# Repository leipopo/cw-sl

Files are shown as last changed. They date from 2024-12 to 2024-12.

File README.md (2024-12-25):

# cw-sl
超轻大导轮，适用于禧玛诺十二速后拨

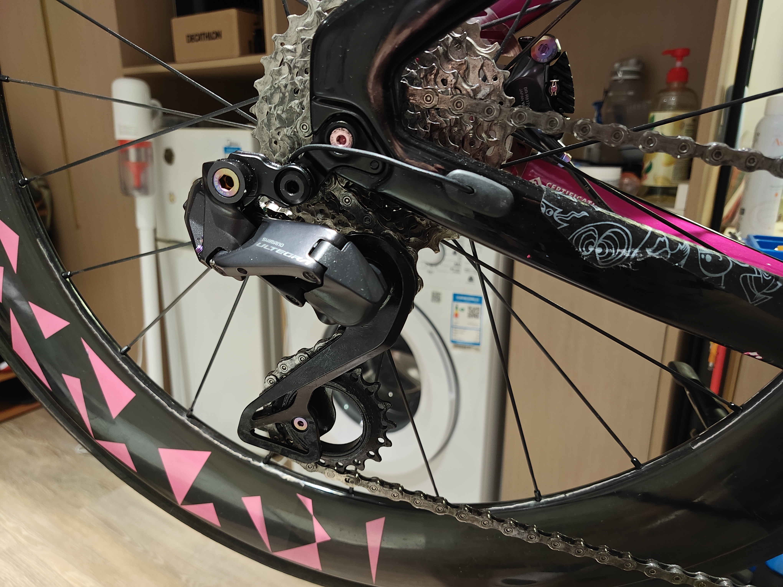
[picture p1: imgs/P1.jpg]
整体效果


# 注意！注意！注意！
本项目定位为超轻毒品件，本设计不做任何质量保证，不承担由此产生的任何安全风险。

# 减重逻辑
禧玛诺原装导轮使用了一颗696rf轴承，此尺寸下的不锈钢轴基本动载约在250lbf左右静载90lbf左右。而大导轮使用的6709轴承的基本动静载约为360/330左右。
参考igus对其生产的塑料轴承和同尺寸普通钢制轴承的动静载的相对比例关系，以及下导轮轴承多工作在低速/静止无冲击的工况，可以初步判断使用塑料6709轴承或许也能满足使用要求。
又进一步分析导轮轴承各部件工作状态：1.内圈局部受高频次的循环载荷，其余地方不受载；2.外圈受低频次的循环载荷，且整个轨道循环频次相同。若采用相同的材质，外圈寿命会远高于内圈。
那直接用塑料做外圈，将齿与外圈做在一起，省去轴承外圈的重量可以进一步减小大导轮重量。于是便有了此项目

# 优化部分

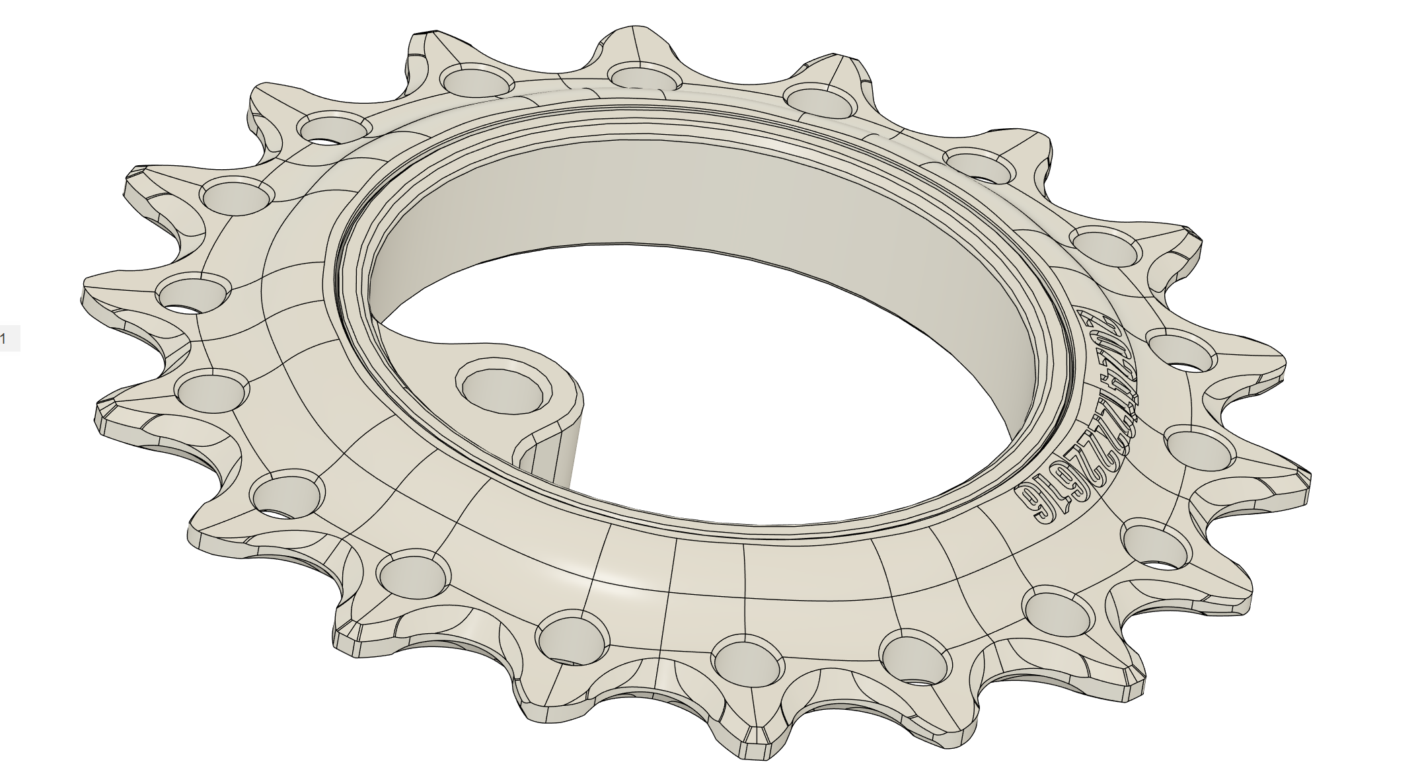
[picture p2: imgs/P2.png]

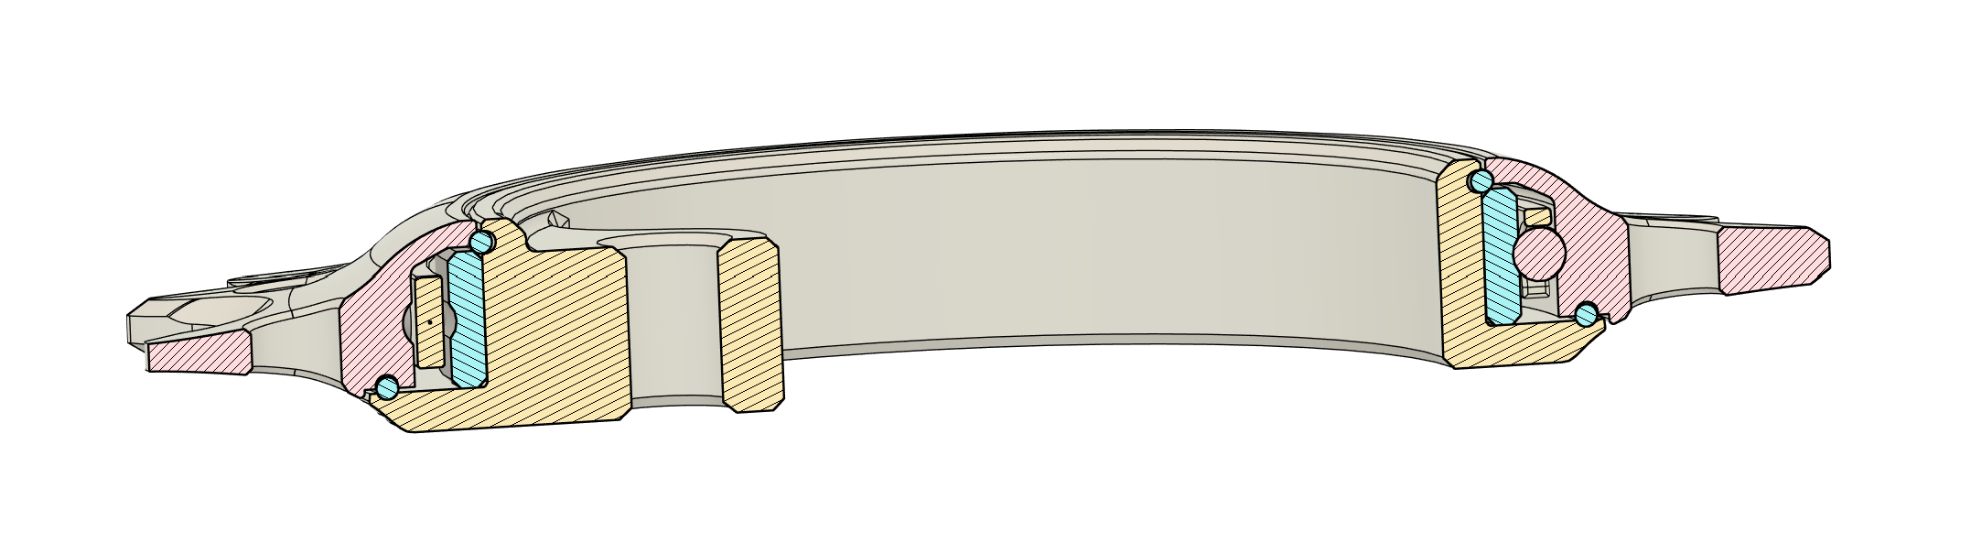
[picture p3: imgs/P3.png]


1. 通过链条路径包络切削出齿形以兼容禧玛诺12s链条的正负齿；
2. 齿端面切割为摆线，优化链条啮入噪声；
3. 齿部与链轮整体光滑，减小风阻；
4. 双面接触式密封，延长维护周期；

# 实测效果
1. 输入功率120w下，损耗功率与原装导轮无差异；
   
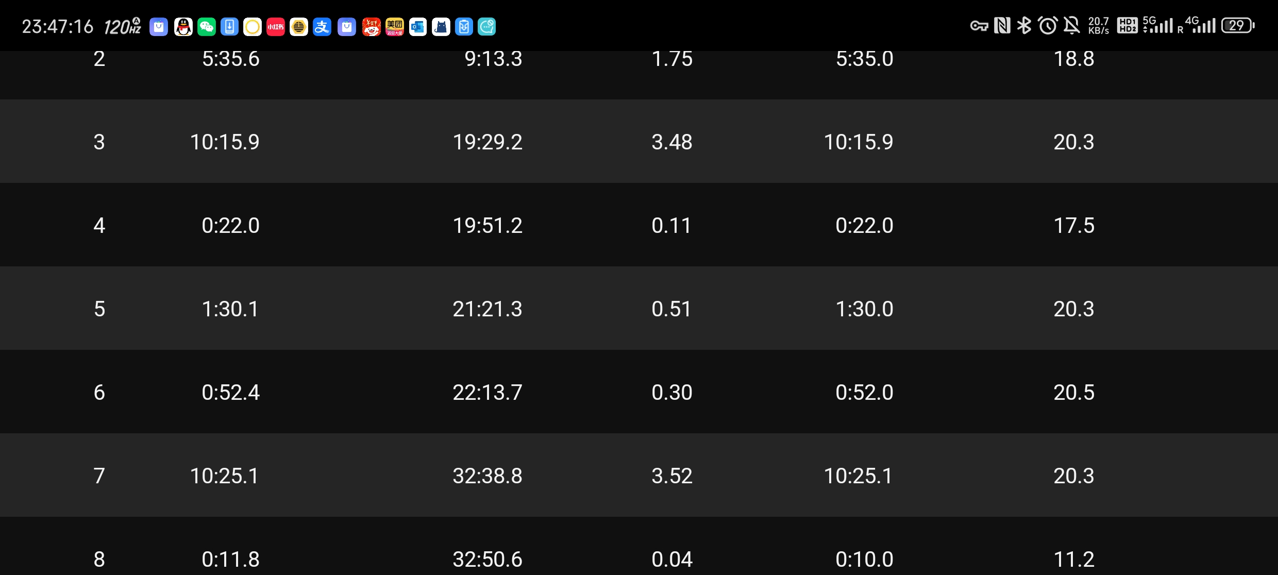
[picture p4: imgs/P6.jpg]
数据1

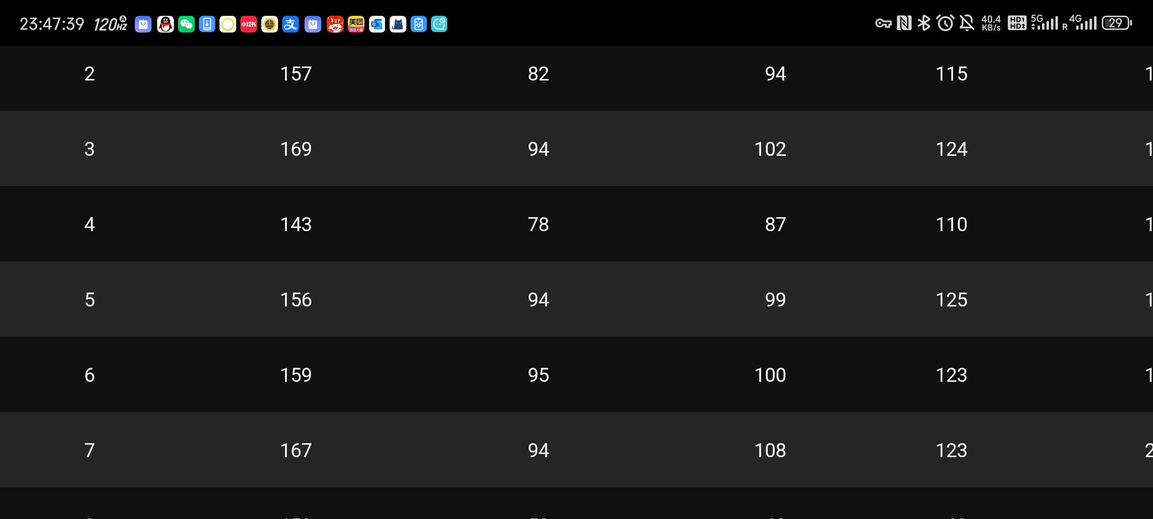
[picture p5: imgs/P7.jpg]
数据2


3. 实测重量21g；
   
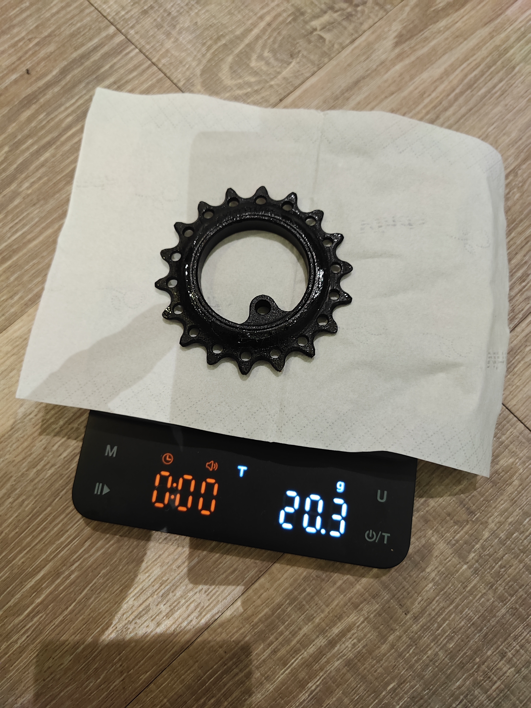
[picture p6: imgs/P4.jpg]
称重


# 制造建议
1. 使用MJF工艺进行打印，并完全清洗；
2. 轴承购买6709陶瓷轴承，滚珠数量33，滚珠直径2.381mm。顶出保持架，将滚珠转到一起即可分离内外圈。建议预先上油再拆开轴承；
3. 由于制造误差和测量误差（滚珠P.C.D尺寸为测量值，非设计值），建议调整滚道直径并打印多个滚道直径的链轮。（本仓库含26.16mm滚道半径以及26.06mm滚道半径的链轮stl）；
4. o型密封圈尺寸及数量：1.内径44mm，线径1mm一根；2.内径53mm，线径1mm一根；
5. 轴承与链轮组合流程与上述拆除轴承流程相同；

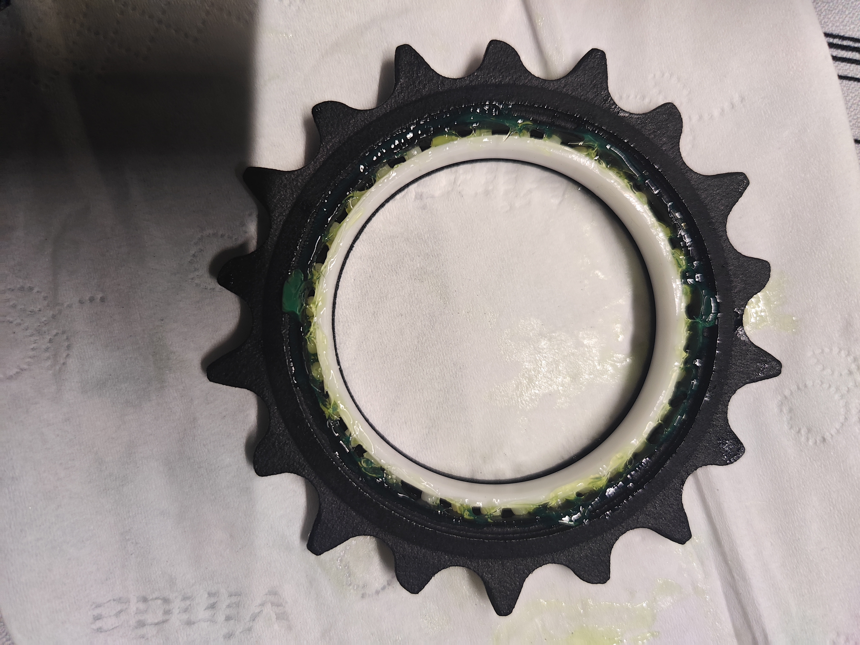
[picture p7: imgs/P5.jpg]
滚珠装入


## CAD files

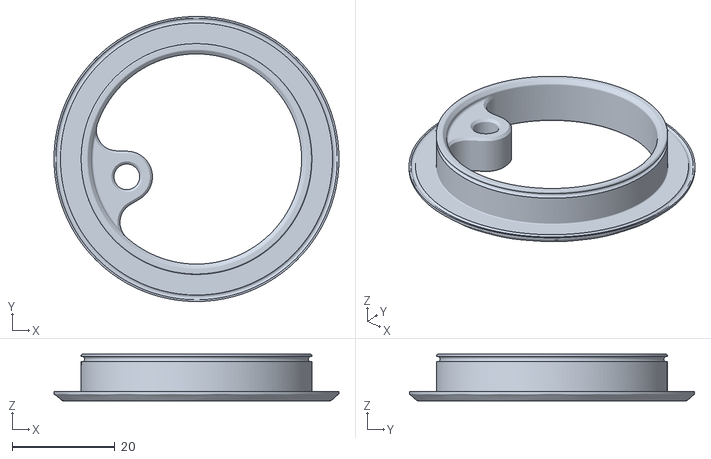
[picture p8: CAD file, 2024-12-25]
stl/bmount.stl
55.6 x 55.6 x 9.15
